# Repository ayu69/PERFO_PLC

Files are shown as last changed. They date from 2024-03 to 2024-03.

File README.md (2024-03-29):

# PERFO_PLC

Vous trouverez l'ensemble des schémas et routage des cartes

Bus Fond de panier :
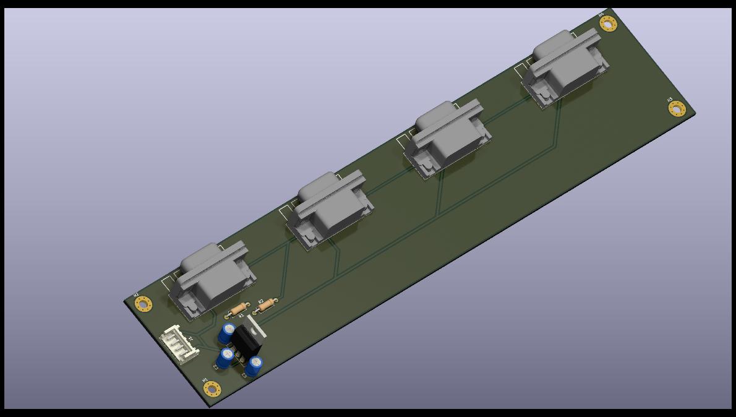
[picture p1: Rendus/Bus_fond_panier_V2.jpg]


CPU :
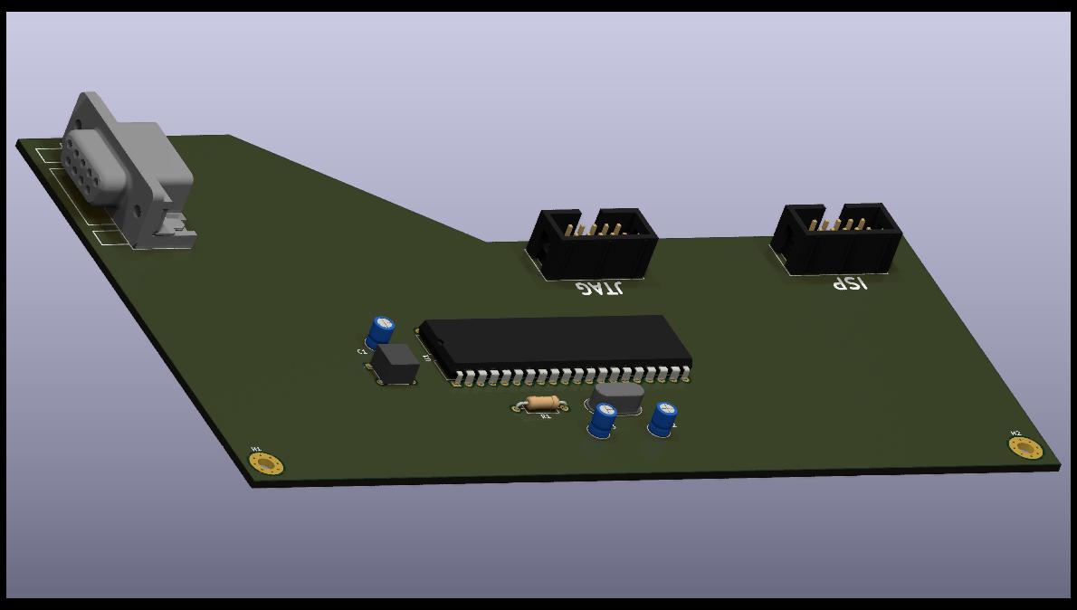
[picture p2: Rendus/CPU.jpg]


Carte Entrée :
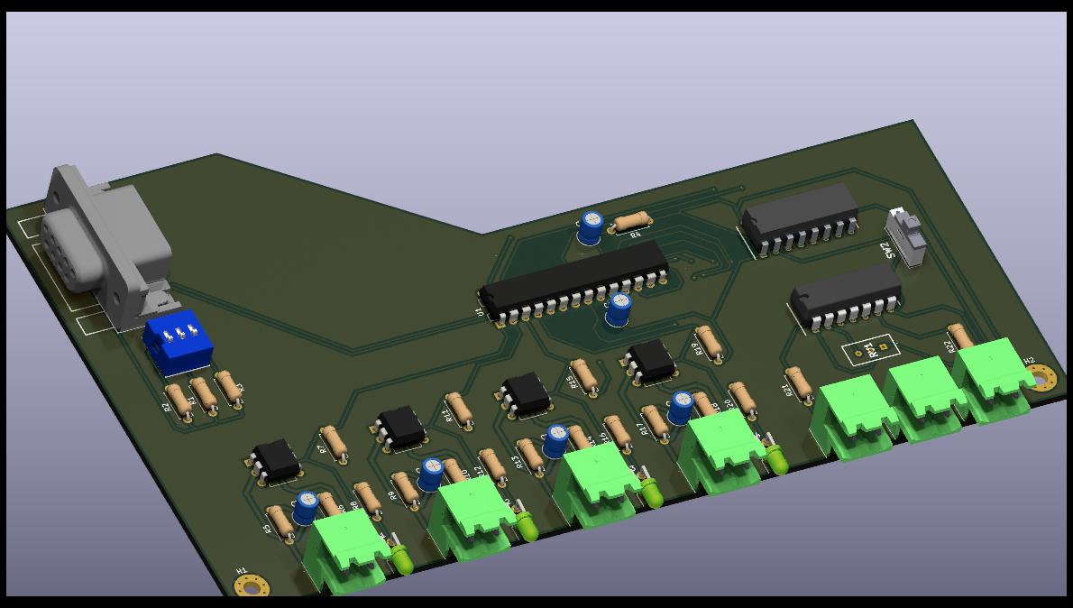
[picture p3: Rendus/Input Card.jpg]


Carte Sorties :
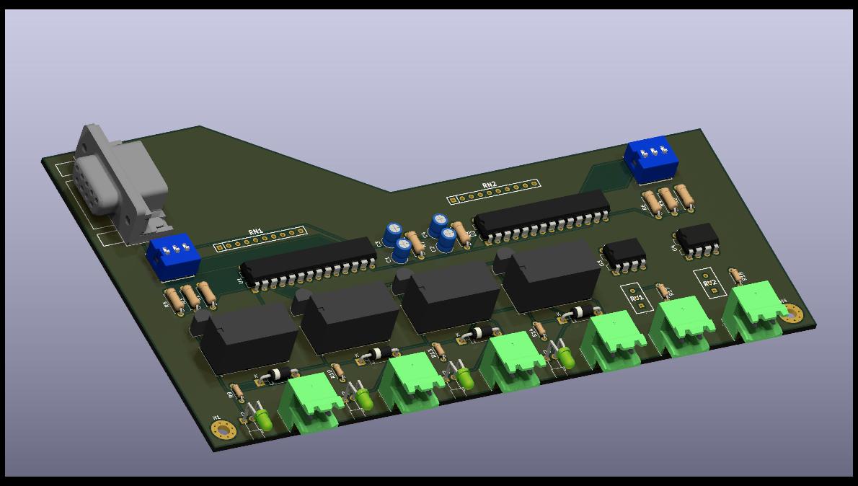
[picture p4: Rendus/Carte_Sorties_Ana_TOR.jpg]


Perfo PLC

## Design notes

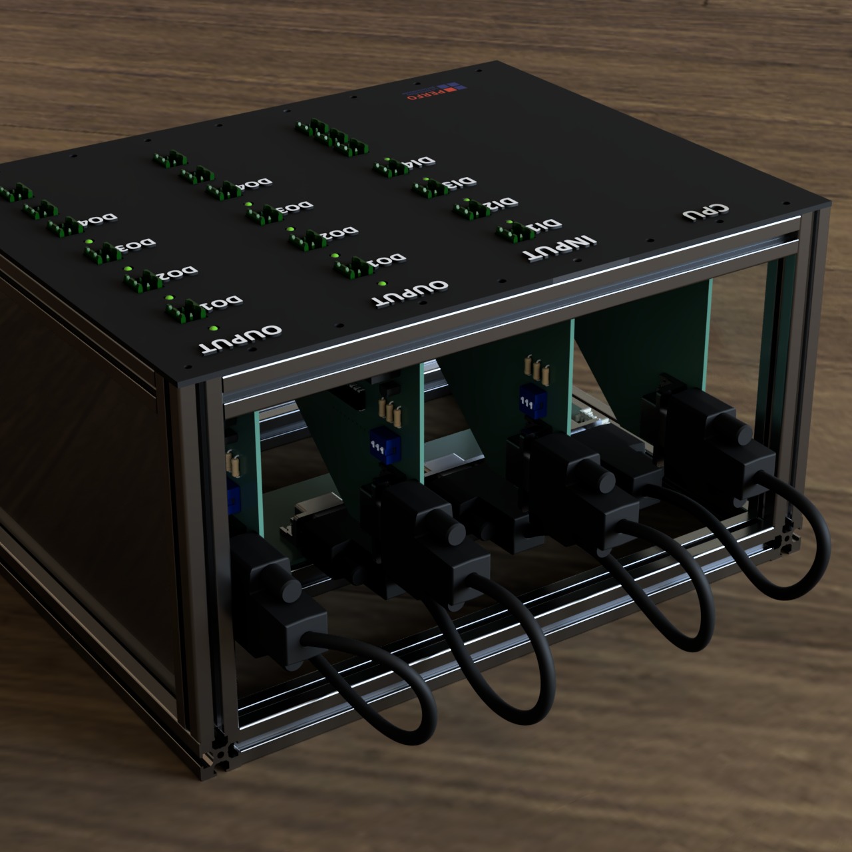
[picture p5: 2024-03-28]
Rendus/Rendu 2 V2.jpeg

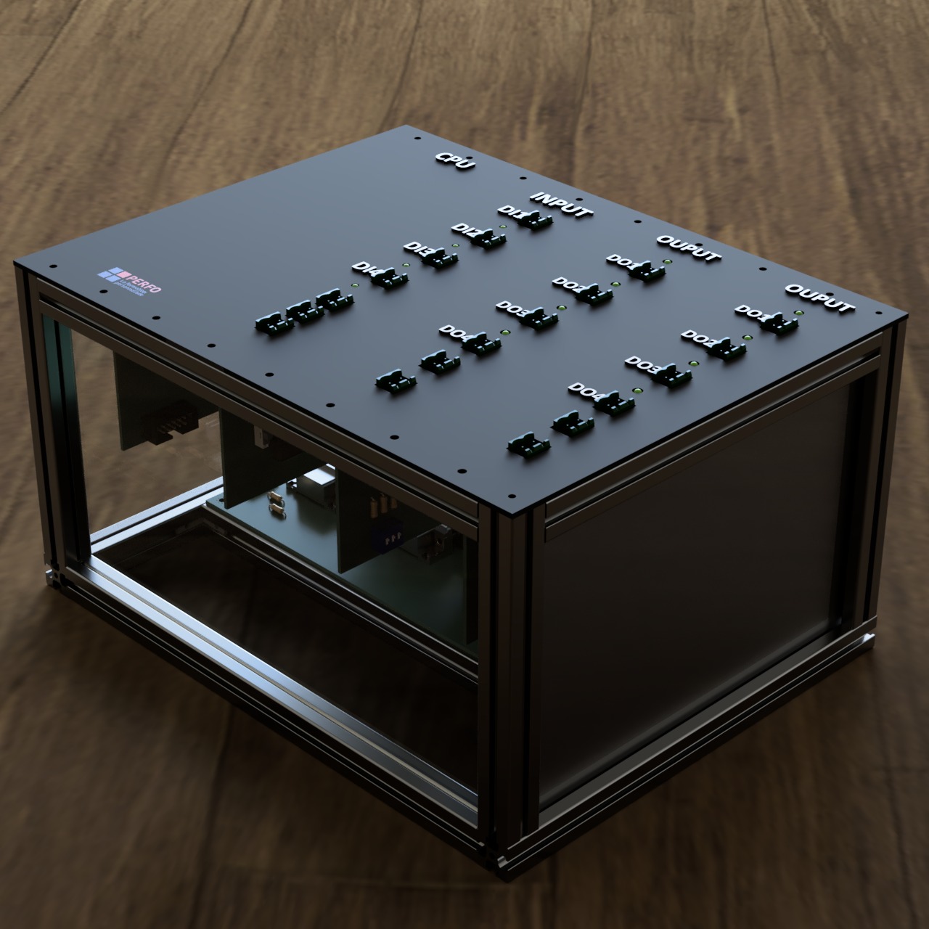
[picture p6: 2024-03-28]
Rendus/Rendu 1 V2.jpeg

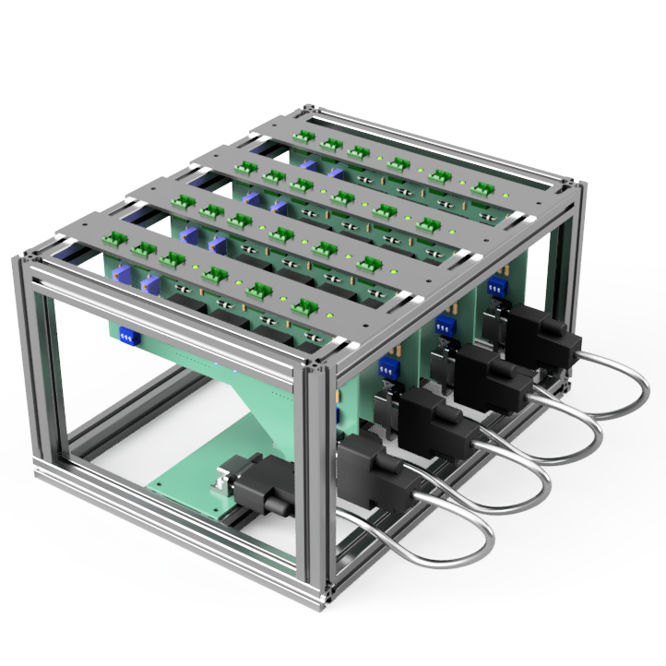
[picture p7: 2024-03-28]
Rendus/Rendu_1.png

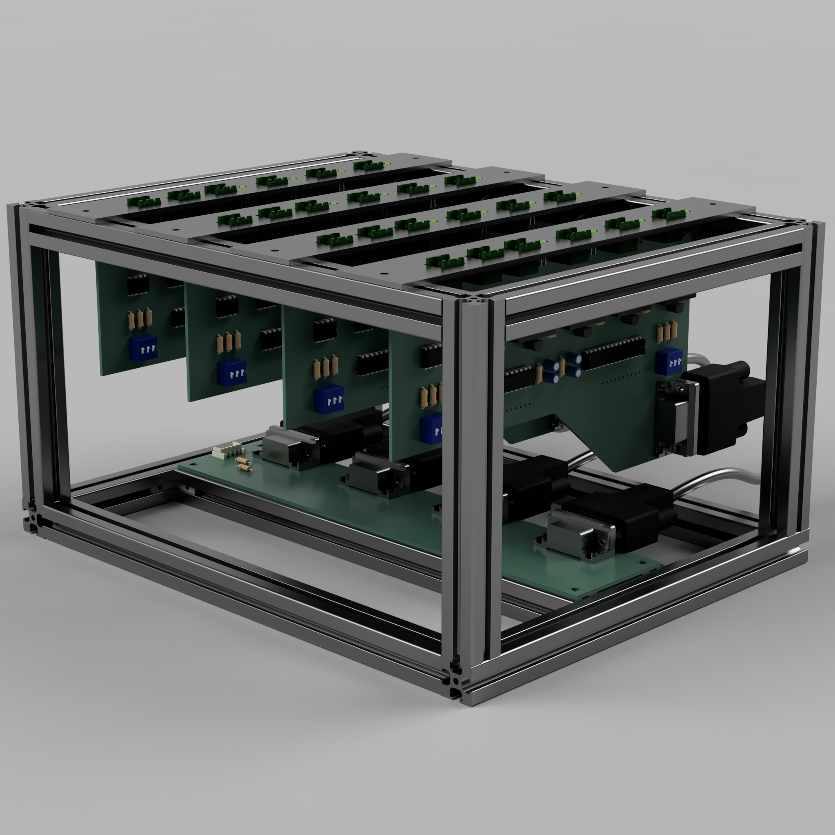
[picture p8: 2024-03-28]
Rendus/Rendu_2.png

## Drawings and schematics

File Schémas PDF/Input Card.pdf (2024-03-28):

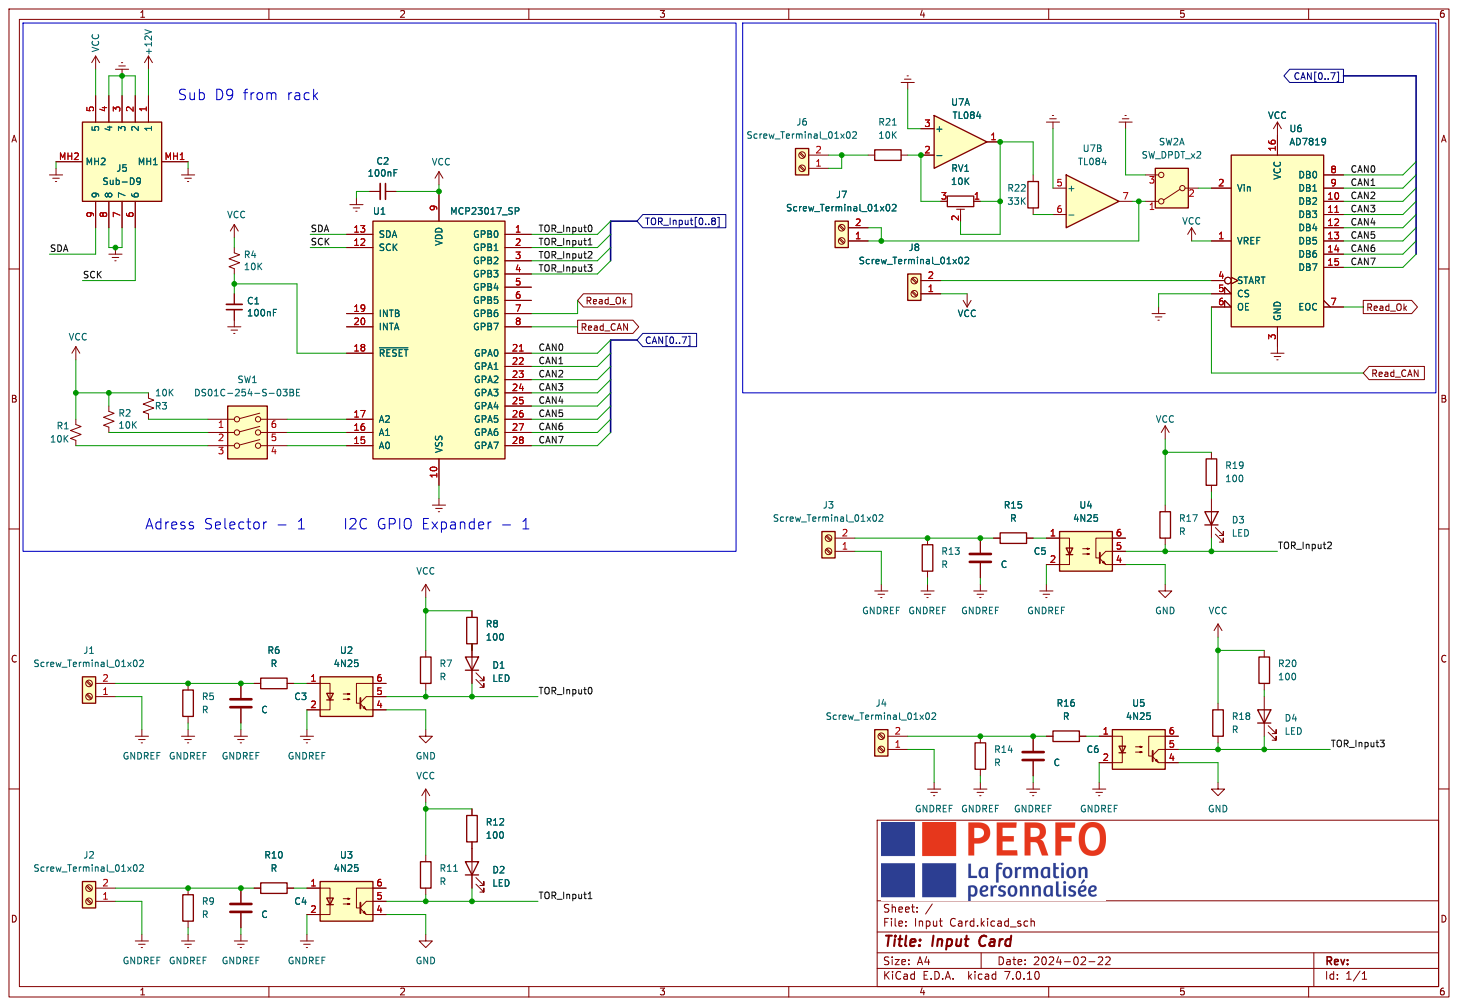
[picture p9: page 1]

3 START 4 CS 5 OE 6 EOC 7 DB0 8 DB1 9 U6AD7819 GNDREF GND

3 START 4 CS 5 OE 6 EOC 7 DB0 8 DB1 9

File: Input Card.kicad_sch Sheet: / 1

Id: 1/1 Title: Input Card

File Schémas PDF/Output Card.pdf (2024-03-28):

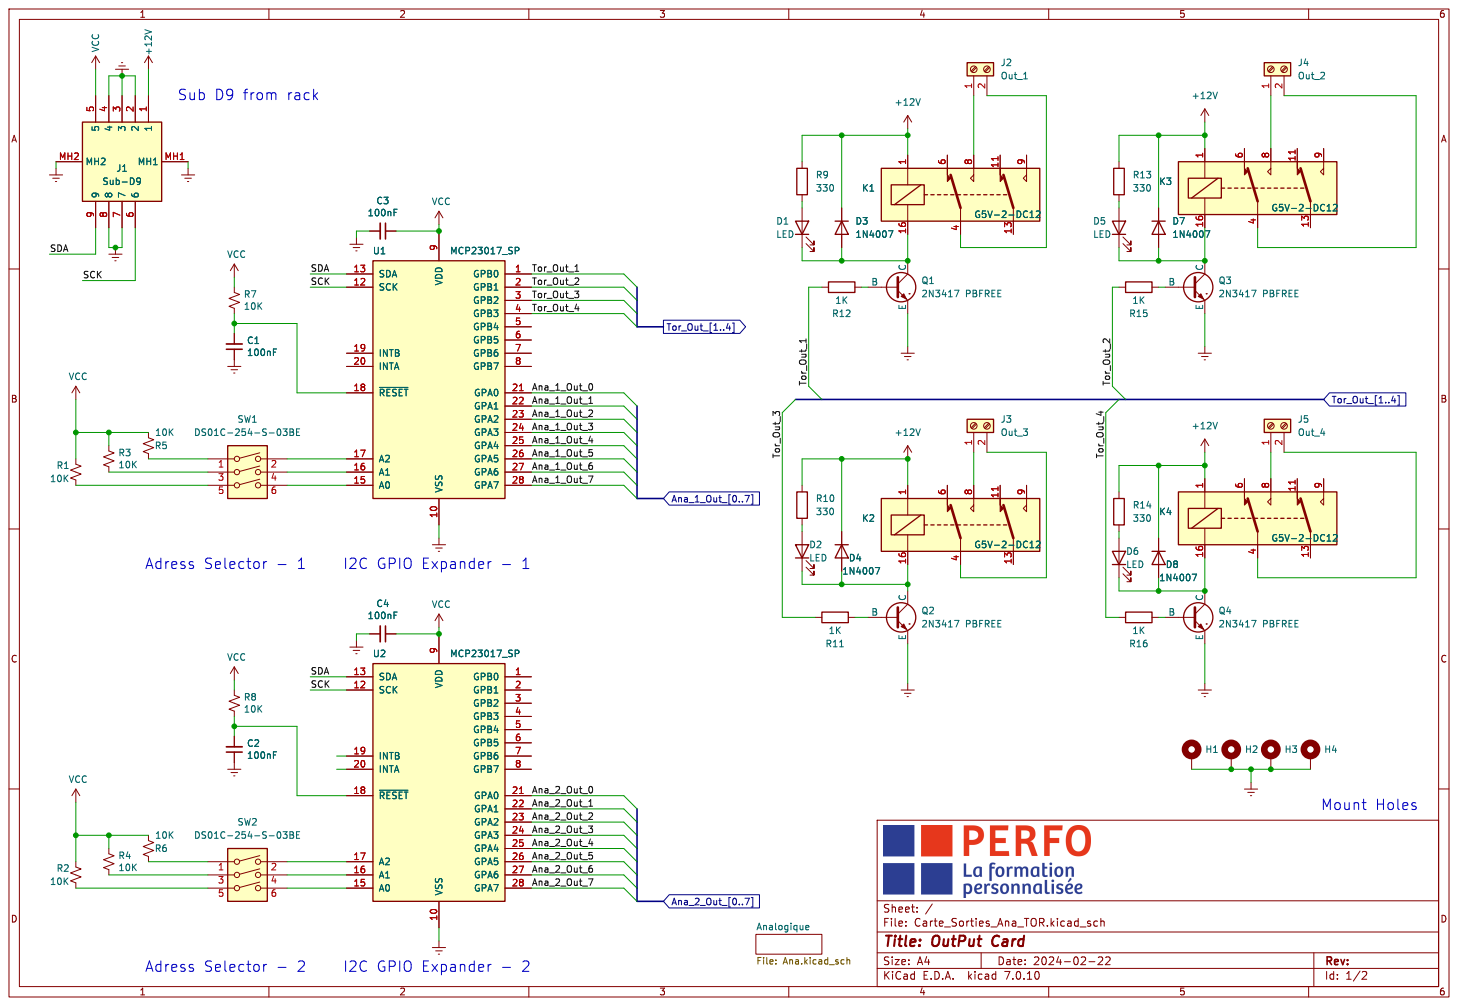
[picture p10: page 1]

9 K3 G5V-2-DC12 GPB0 1 VSS 10 SCK 12 SDA 13 A0 15 A1 16 A2 17 ~{RESET} 18

9 K2 G5V-2-DC12 VCC GPB0 1 VSS 10 SCK 12 SDA 13 A0 15 A1 16 A2 17 ~{RESET} 18

File: Carte_Sorties_Ana_TOR.kicad_sch Sheet: / Analogique File: Ana.kicad_sch

Id: 1/2 Title: OutPut Card

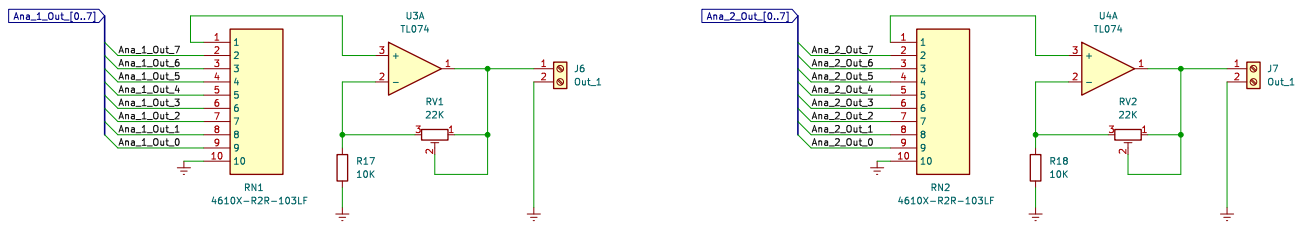
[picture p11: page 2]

File: Ana.kicad_sch Sheet: /Analogique/
Id: 2/2 Title: OutPut Card

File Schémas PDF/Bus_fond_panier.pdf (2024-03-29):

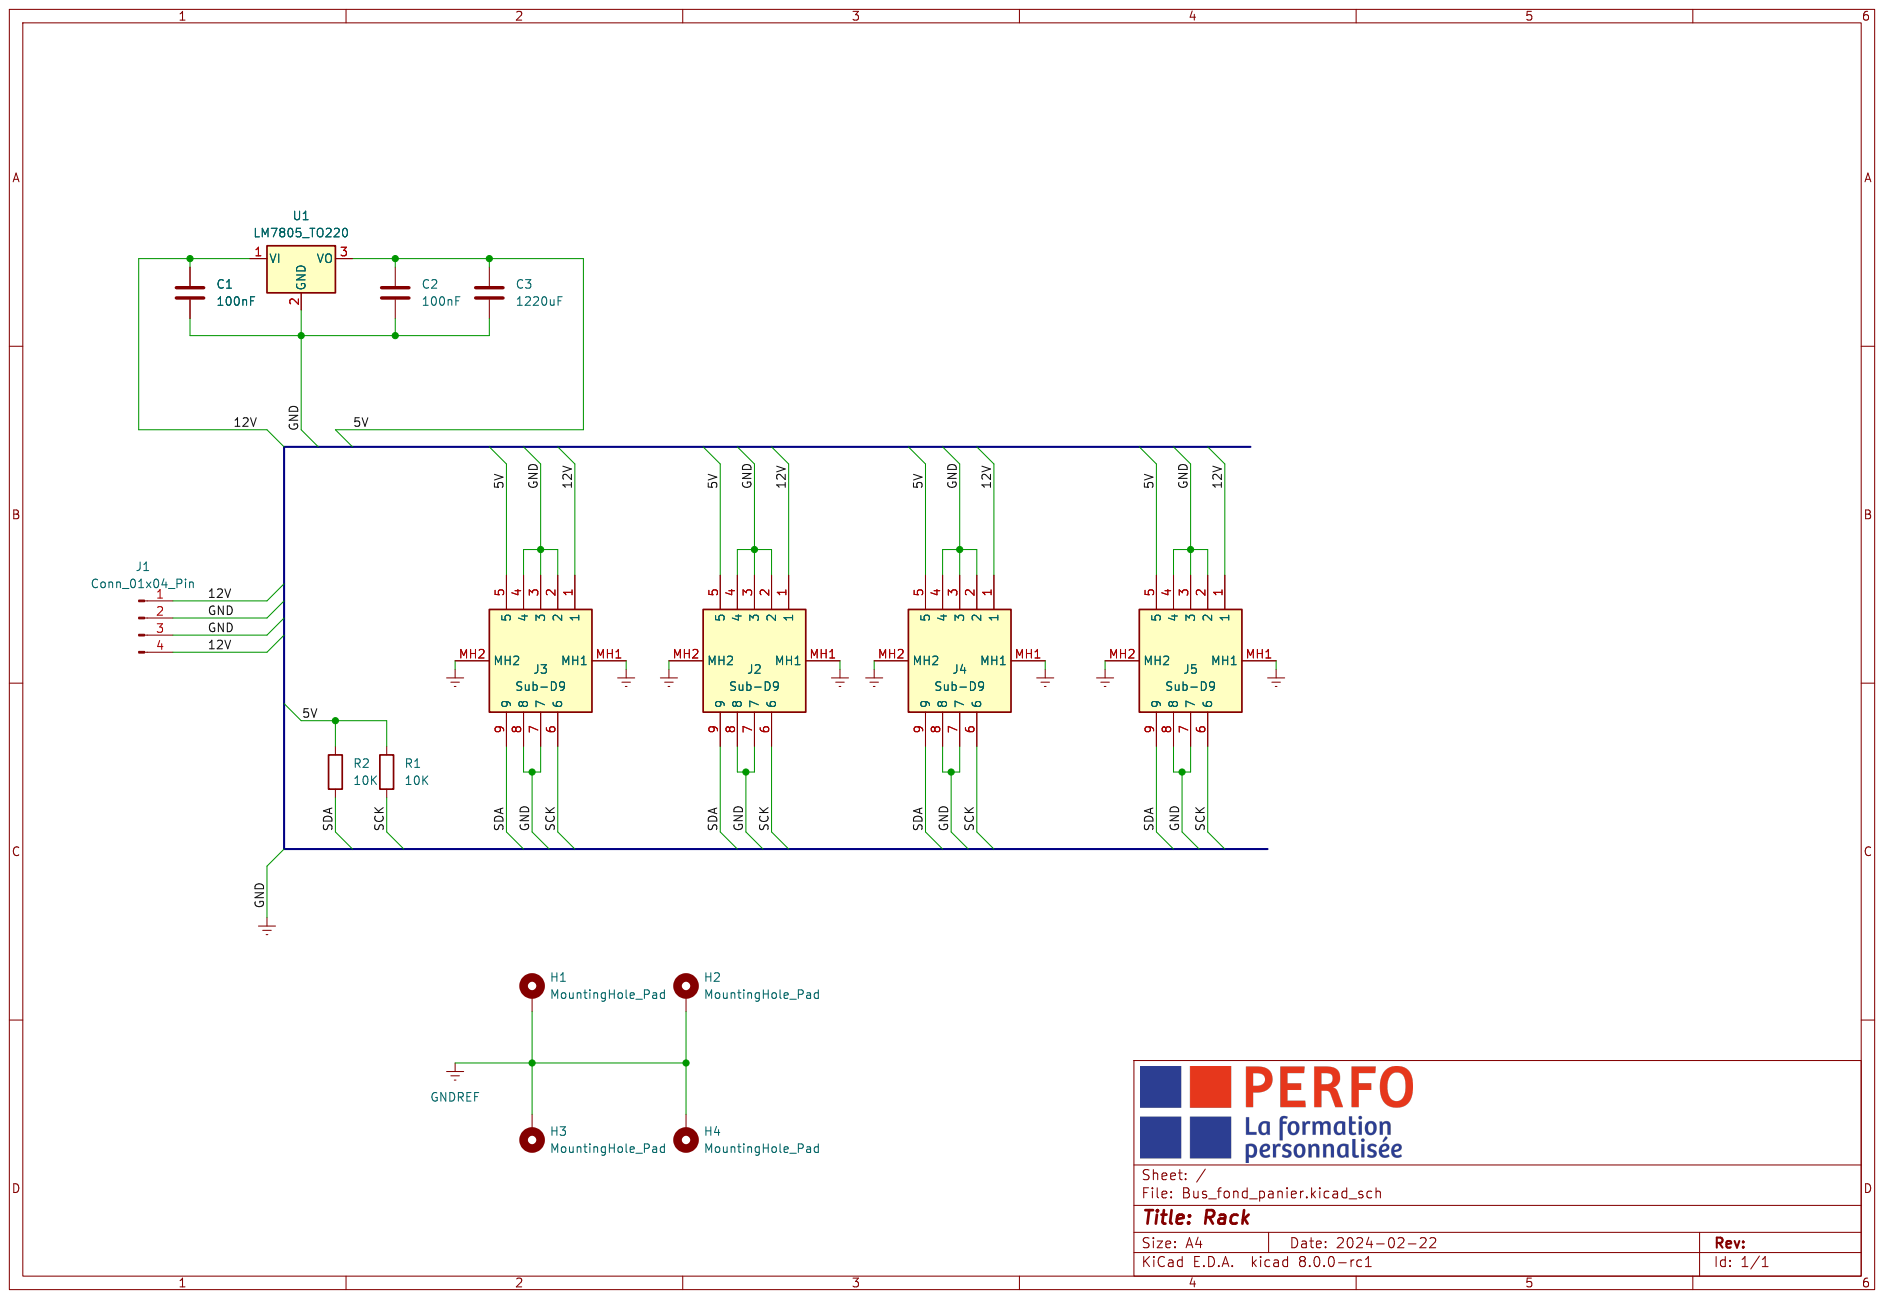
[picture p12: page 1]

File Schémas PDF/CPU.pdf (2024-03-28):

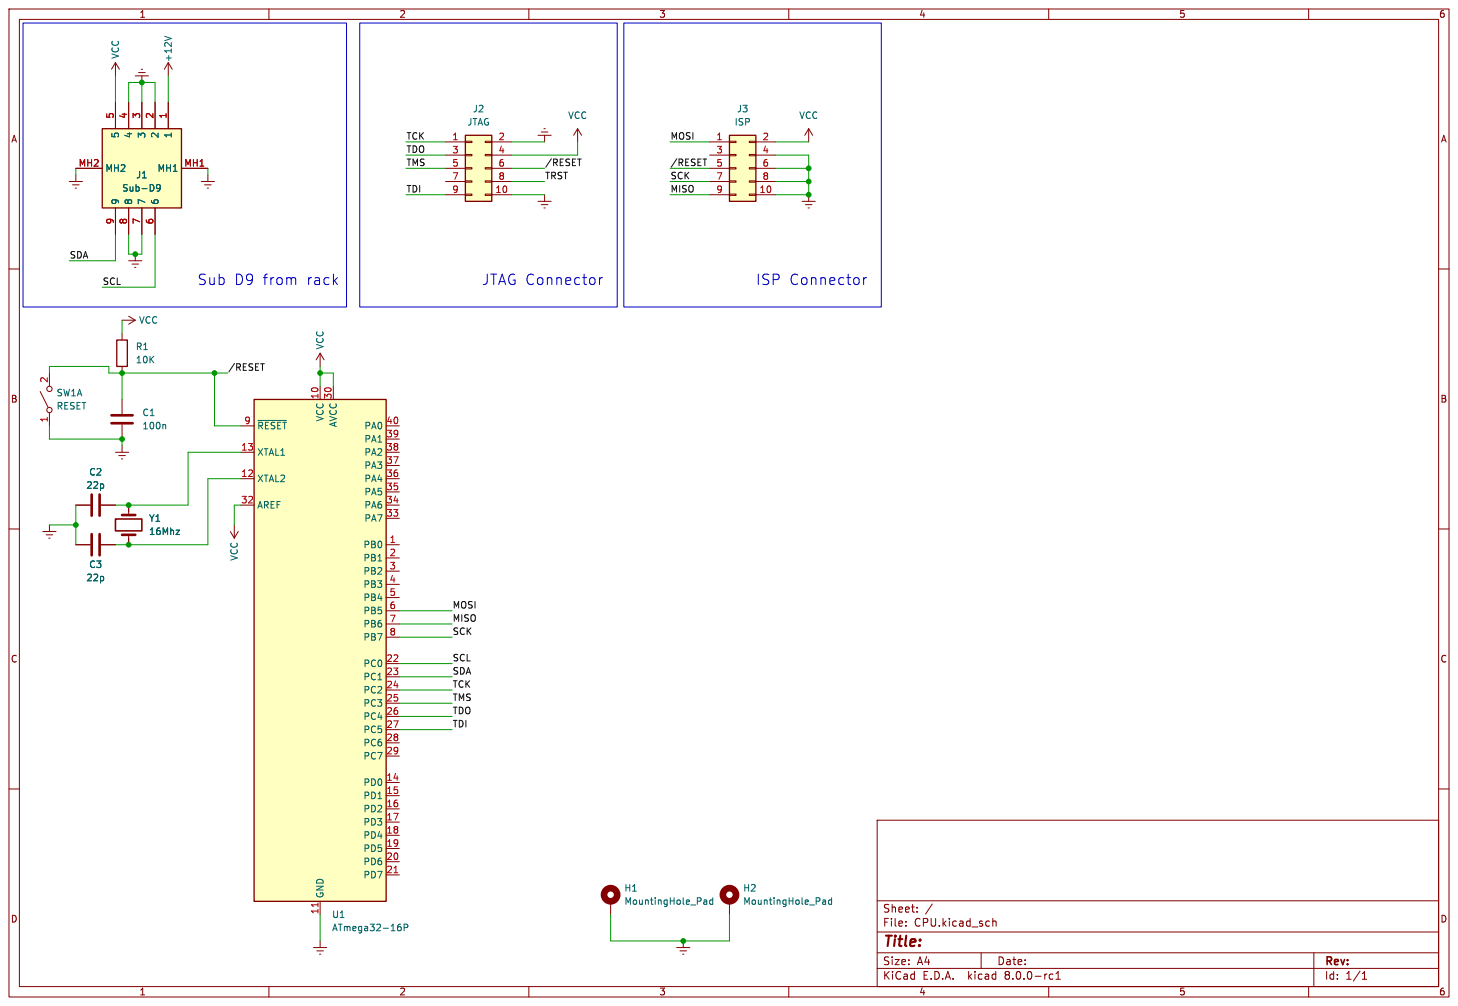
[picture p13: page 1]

/RESET SCK MISO MOSI TMS

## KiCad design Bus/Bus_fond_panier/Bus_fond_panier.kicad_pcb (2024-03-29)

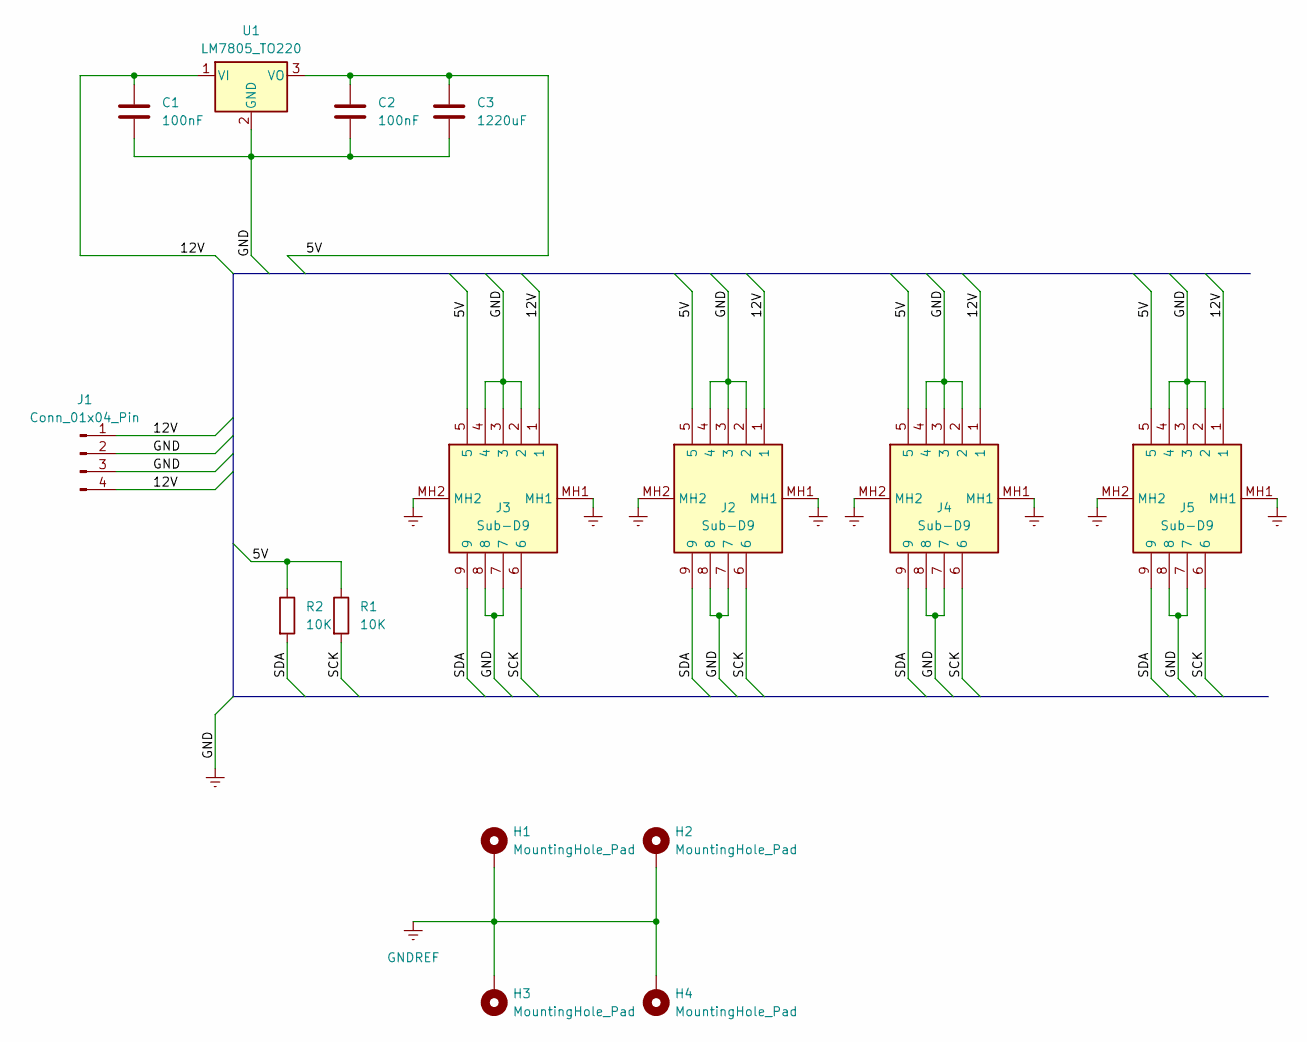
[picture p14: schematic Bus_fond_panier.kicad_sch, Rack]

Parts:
C1, C2: 100nF; C_Radial_D4.0mm_H7.0mm_P1.50mm
C3: 1220uF; C_Radial_D4.0mm_H7.0mm_P1.50mm
H1, H2, H3, H4: MountingHole_Pad; MountingHole_3.2mm_M3_Pad_Via
J1: Conn_01x04_Pin; JST_EH_S4B-EH_1x04_P2.50mm_Horizontal
J2, J3, J4, J5: Sub-D9; NFD17E09SAFC1DA; Manufacturer_Part_Number NFD17E09SAFC1DA
R1, R2: 10K; R_Axial_DIN0207_L6.3mm_D2.5mm_P10.16mm_Horizontal
U1: LM7805_TO220; TO-220-3_Vertical

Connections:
/5V: C2.1, C3.1, J2.5, J3.5, J4.5, J5.5, R1.1, R2.1, U1.3 (VO)
/12V: C1.1, J1.1, J1.4, J2.1, J3.1, J4.1, J5.1, U1.1 (VI)
/SCK: J2.6, J3.6, J4.6, J5.6, R1.2
/SDA: J2.9, J3.9, J4.9, J5.9, R2.2
GNDREF: C1.2, C2.2, C3.2, H1.1, H2.1, H3.1, H4.1, J1.2, J1.3, J2.2, J2.3, J2.4, J2.7, J2.8, J2.MH1, J2.MH2, J3.2, J3.3, J3.4, J3.7, J3.8, J3.MH1, J3.MH2, J4.2, J4.3, J4.4, J4.7, J4.8, J4.MH1, J4.MH2, J5.2, J5.3, J5.4, J5.7, J5.8, J5.MH1, J5.MH2, U1.2 (GND)

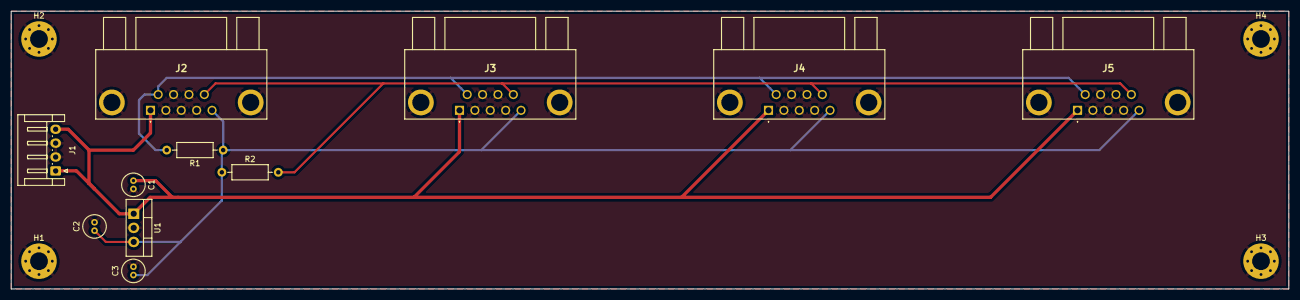
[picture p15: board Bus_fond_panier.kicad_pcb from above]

Board: 2 copper layers, 230.0 x 50.0 mm, 15 parts (0 on the bottom side), 5 nets.

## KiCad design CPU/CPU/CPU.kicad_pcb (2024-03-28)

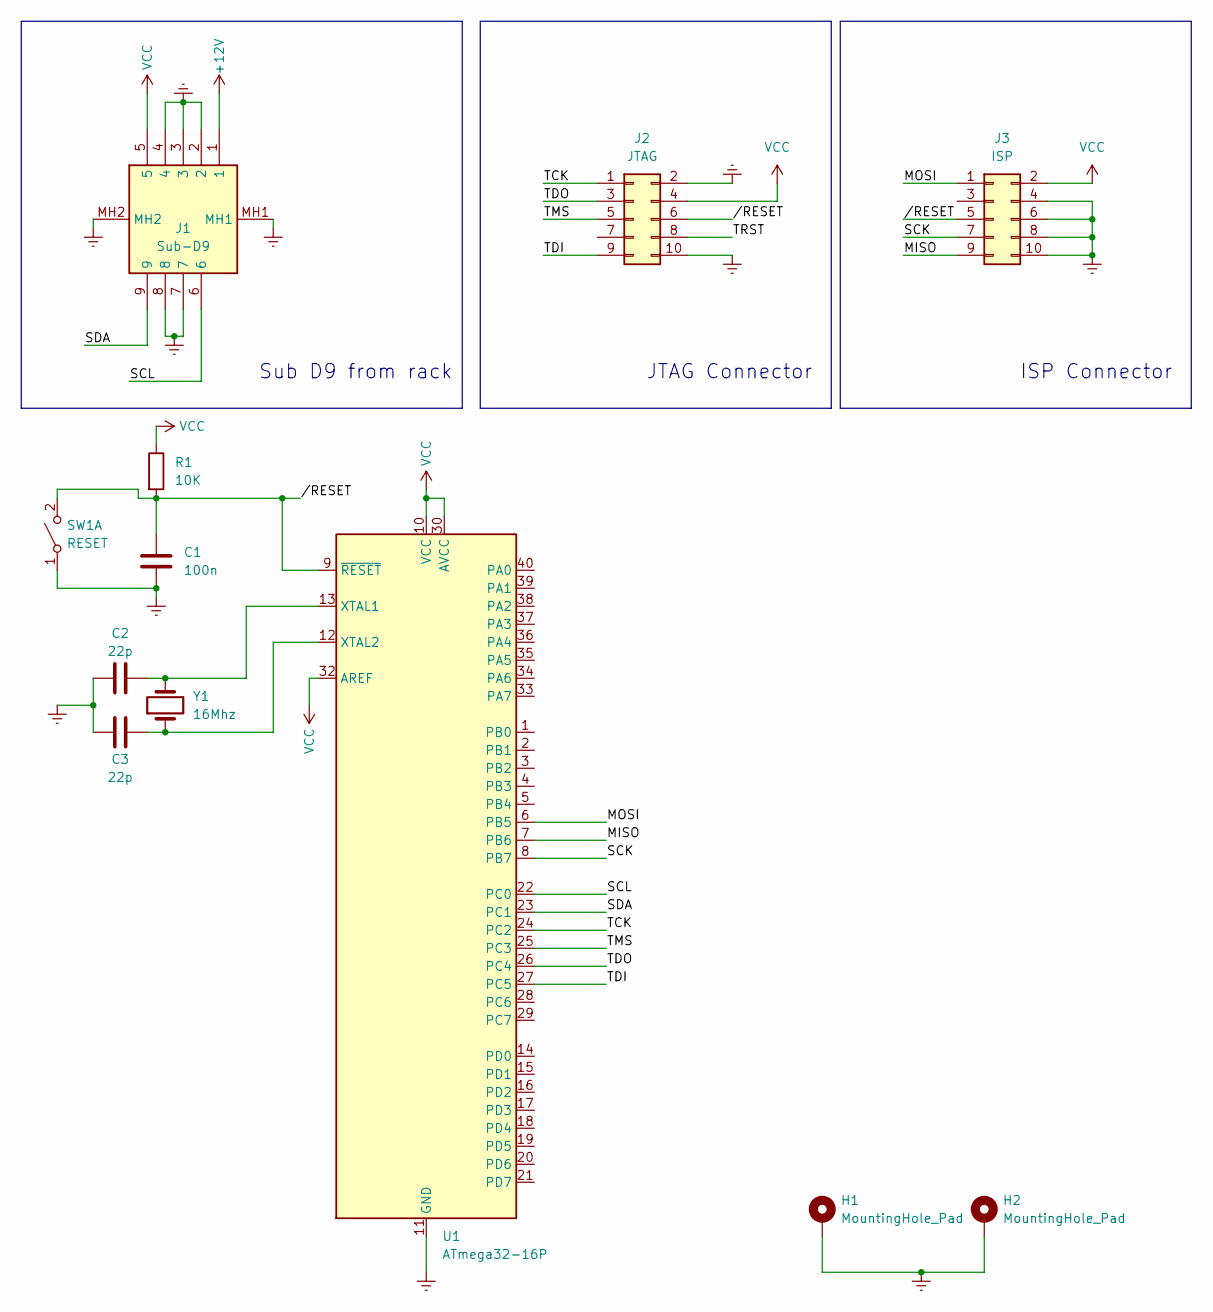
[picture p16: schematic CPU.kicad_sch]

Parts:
C1: 100n; C_Radial_D4.0mm_H5.0mm_P1.50mm
C2, C3: 22p; C_Radial_D4.0mm_H5.0mm_P1.50mm
H1, H2: MountingHole_Pad; MountingHole_3.2mm_M3_Pad_Via
J1: Sub-D9; NFD17E09SAFC1DA; Manufacturer_Part_Number NFD17E09SAFC1DA
J2: JTAG; IDC-Header_2x05_P2.54mm_Vertical
J3: ISP; IDC-Header_2x05_P2.54mm_Vertical
R1: 10K; R_Axial_DIN0207_L6.3mm_D2.5mm_P10.16mm_Horizontal
SW1: RESET; PTS645SH952LFS
U1: ATmega32-16P; DIP-40_W15.24mm
Y1: 16Mhz; Crystal_HC49-4H_Vertical

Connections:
+12V: J1.1
/MISO: J3.9, U1.7 (PB6)
/MOSI: J3.1, U1.6 (PB5)
/SCK: J3.7, U1.8 (PB7)
/SCL: J1.6, U1.22 (PC0)
/SDA: J1.9, U1.23 (PC1)
/TCK: J2.1, U1.24 (PC2)
/TDI: J2.9, U1.27 (PC5)
/TDO: J2.3, U1.26 (PC4)
/TMS: J2.5, U1.25 (PC3)
/TRST: J2.8
//RESET: C1.1, J2.6, J3.5, R1.2, SW1.2 (B), U1.9 (~RESET)
GNDREF: C1.2, C2.1, C3.1, H1.1, H2.1, J1.2, J1.3, J1.4, J1.7, J1.8, J1.MH1, J1.MH2, J2.2, J2.10, J3.4, J3.6, J3.8, J3.10, SW1.1 (A), U1.11 (GND), U1.31 (GND)
unnamed: C2.2, U1.13 (XTAL1), Y1.2
unnamed: C3.2, U1.12 (XTAL2), Y1.1
VCC: J1.5, J2.4, J3.2, R1.1, U1.10 (VCC), U1.30 (AVCC), U1.32 (AREF)

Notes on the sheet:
JTAG Connector
Sub D9 from rack
ISP Connector

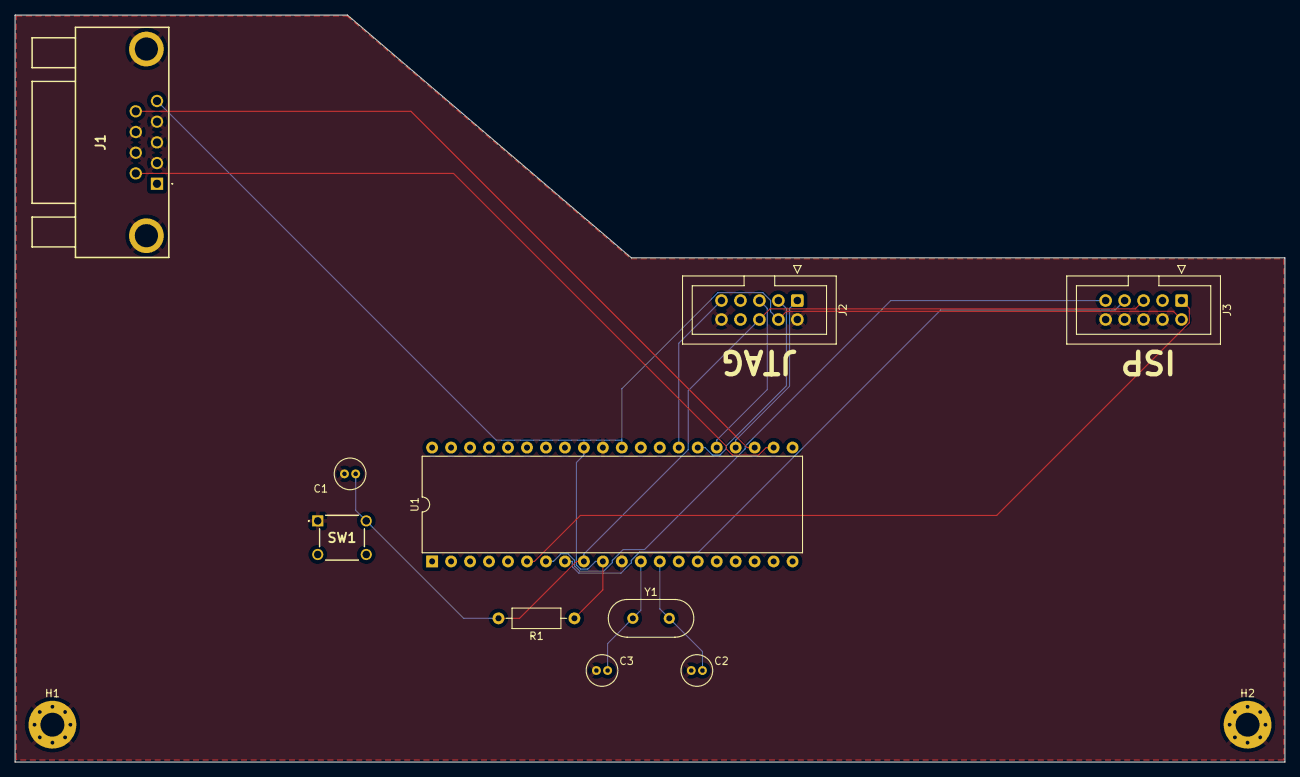
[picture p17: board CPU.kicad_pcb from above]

Board: 2 copper layers, 170.0 x 100.0 mm, 12 parts (0 on the bottom side), 14 nets.

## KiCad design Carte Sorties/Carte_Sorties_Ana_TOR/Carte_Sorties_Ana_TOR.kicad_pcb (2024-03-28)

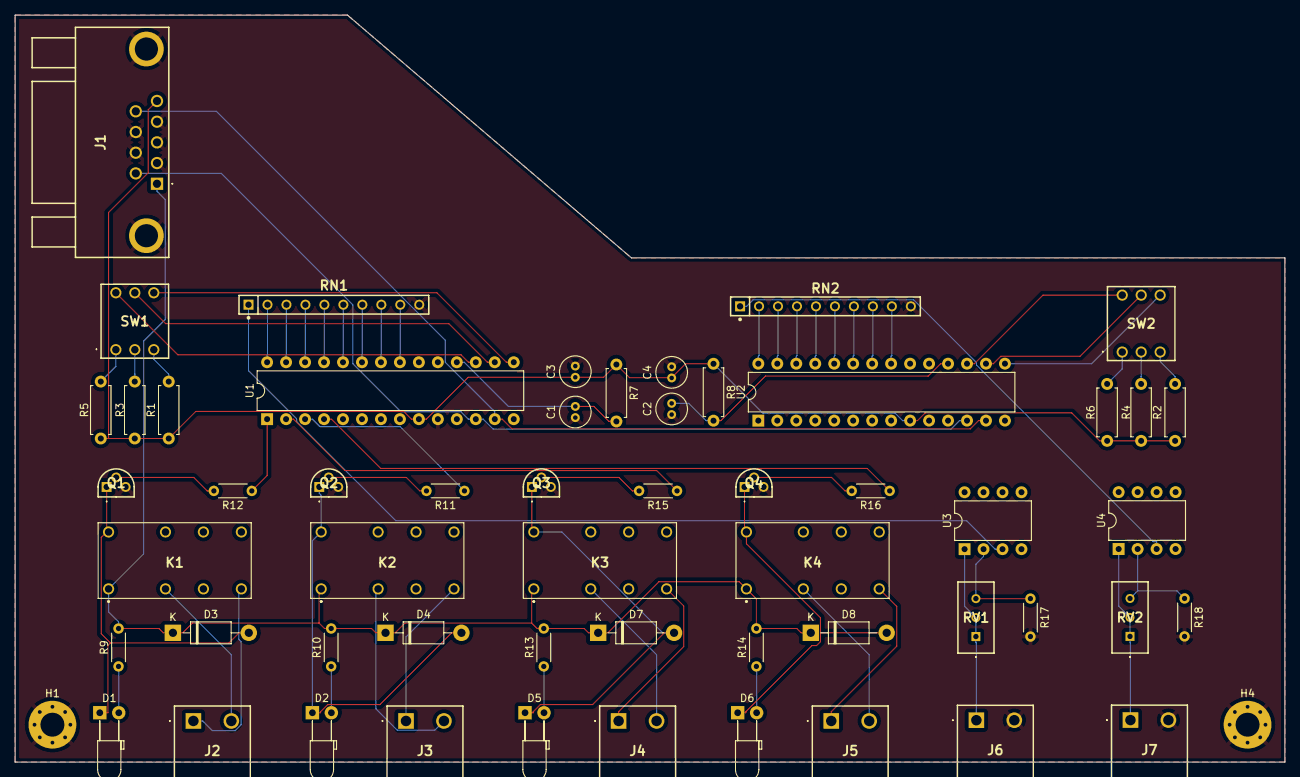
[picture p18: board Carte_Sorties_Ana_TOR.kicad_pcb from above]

Board: 2 copper layers, 170.0 x 100.0 mm, 57 parts (0 on the bottom side), 65 nets.

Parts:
C1, C2, C3, C4: 100nF; C_Radial_D4.0mm_H5.0mm_P1.50mm
D1, D2, D5, D6: LED; LED_D3.0mm_Horizontal_O3.81mm_Z6.0mm
D3, D4, D7, D8: 1N4007; D_DO-41_SOD81_P10.16mm_Horizontal
H1, H4: MountingHole_Pad; MountingHole_3.2mm_M3_Pad_Via
J1: Sub-D9; NFD17E09SAFC1DA
J2, J6, J7: Out_1; 1735882
J3: Out_3; 1735882
J4: Out_2; 1735882
J5: Out_4; 1735882
K1, K2, K3, K4: G5V-2-DC12; G5V23DC
Q1, Q2, Q3, Q4: 2N3417 PBFREE; 2N3417PBFREE
R1, R2, R3, R4, R5, R6, R7, R8: 10K; R_Axial_DIN0207_L6.3mm_D2.5mm_P7.62mm_Horizontal
R9, R10, R13, R14: 330; R_Axial_DIN0204_L3.6mm_D1.6mm_P5.08mm_Horizontal
R11, R12, R15, R16: 1K; R_Axial_DIN0204_L3.6mm_D1.6mm_P5.08mm_Horizontal
R17, R18: 10K; R_Axial_DIN0204_L3.6mm_D1.6mm_P5.08mm_Horizontal
RN1, RN2: 4610X-R2R-103LF; SIP249W51P254L2535H508Q10P
RV1, RV2: 22K; 3296W1223LF
SW1, SW2: DS01C-254-S-03BE; DS01C254S03BE
U1, U2: MCP23017_SP; DIP-28_W7.62mm
U3, U4: TL074; DIP-8_W7.62mm

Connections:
+12V: D3.1 (K), D4.1 (K), D7.1 (K), D8.1 (K), J1.1, K1.1, K2.1, K3.1, K4.1, R9.2, R10.2, R13.2, R14.2
/SCK: J1.6, U1.12 (SCK), U2.12 (SCK)
/SDA: J1.9, U1.13 (SDA), U2.13 (SDA)
Ana_1_Out_0: RN1.9, U1.21 (GPA0)
Ana_1_Out_1: RN1.8, U1.22 (GPA1)
Ana_1_Out_2: RN1.7, U1.23 (GPA2)
Ana_1_Out_3: RN1.6, U1.24 (GPA3)
Ana_1_Out_4: RN1.5, U1.25 (GPA4)
Ana_1_Out_5: RN1.4, U1.26 (GPA5)
Ana_1_Out_6: RN1.3, U1.27 (GPA6)
Ana_1_Out_7: RN1.2, U1.28 (GPA7)
Ana_2_Out_0: RN2.9, U2.21 (GPA0)
Ana_2_Out_1: RN2.8, U2.22 (GPA1)
Ana_2_Out_2: RN2.7, U2.23 (GPA2)
Ana_2_Out_3: RN2.6, U2.24 (GPA3)
Ana_2_Out_4: RN2.5, U2.25 (GPA4)
Ana_2_Out_5: RN2.4, U2.26 (GPA5)
Ana_2_Out_6: RN2.3, U2.27 (GPA6)
Ana_2_Out_7: RN2.2, U2.28 (GPA7)
GNDREF: C1.1, C2.1, C3.2, C4.2, H1.1, H4.1, J1.2, J1.3, J1.4, J1.7, J1.8, J1.MH1, J1.MH2, J6.2, J7.2, Q1.3 (E), Q2.3 (E), Q3.3 (E), Q4.3 (E), R17.2, R18.2, RN1.10, RN2.10, U1.10 (VSS), U2.10 (VSS)
unnamed: D1.2 (A), R9.1
unnamed: D1.1 (K), D3.2 (A), K1.16, Q1.1 (C)
unnamed: D2.2 (A), R10.1
unnamed: D2.1 (K), D4.2 (A), K2.16, Q2.1 (C)
unnamed: D5.2 (A), R13.1
unnamed: D5.1 (K), D7.2 (A), K3.16, Q3.1 (C)
unnamed: D6.2 (A), R14.1
unnamed: D6.1 (K), D8.2 (A), K4.16, Q4.1 (C)
unnamed: J2.1, K1.8
unnamed: J2.2, K1.4
unnamed: J3.1, K2.8
unnamed: J3.2, K2.4
unnamed: J4.1, K3.8
unnamed: J4.2, K3.4
unnamed: J5.1, K4.8
unnamed: J5.2, K4.4
unnamed: J6.1, RV1.1, RV1.2, U3.1
unnamed: J7.1, RV2.1, RV2.2, U4.1
unnamed: Q1.2 (B), R12.2
unnamed: Q2.2 (B), R11.2
unnamed: Q3.2 (B), R15.2
unnamed: Q4.2 (B), R16.2
unnamed: R1.2, SW1.5
unnamed: R2.2, SW2.5
unnamed: R3.2, SW1.3
unnamed: R4.2, SW2.3
unnamed: R5.1, SW1.1
unnamed: R6.1, SW2.1
unnamed: SW1.6, U1.15 (A0)
unnamed: SW1.4, U1.16 (A1)
unnamed: SW1.2, U1.17 (A2)
unnamed: C1.2, R7.2, U1.18 (~RESET)
unnamed: SW2.6, U2.15 (A0)
unnamed: SW2.4, U2.16 (A1)
unnamed: SW2.2, U2.17 (A2)
unnamed: C2.2, R8.2, U2.18 (~RESET)
unnamed: RN1.1, U3.3 (+)
unnamed: R17.1, RV1.3, U3.2 (-)
unnamed: RN2.1, U4.3 (+)
unnamed: R18.1, RV2.3, U4.2 (-)
Tor_Out_1: R12.1, U1.1 (GPB0)
Tor_Out_2: R15.1, U1.2 (GPB1)
Tor_Out_3: R11.1, U1.3 (GPB2)
Tor_Out_4: R16.1, U1.4 (GPB3)
VCC: C3.1, C4.1, J1.5, R1.1, R2.1, R3.1, R4.1, R5.2, R6.2, R7.1, R8.1, U1.9 (VDD), U2.9 (VDD)

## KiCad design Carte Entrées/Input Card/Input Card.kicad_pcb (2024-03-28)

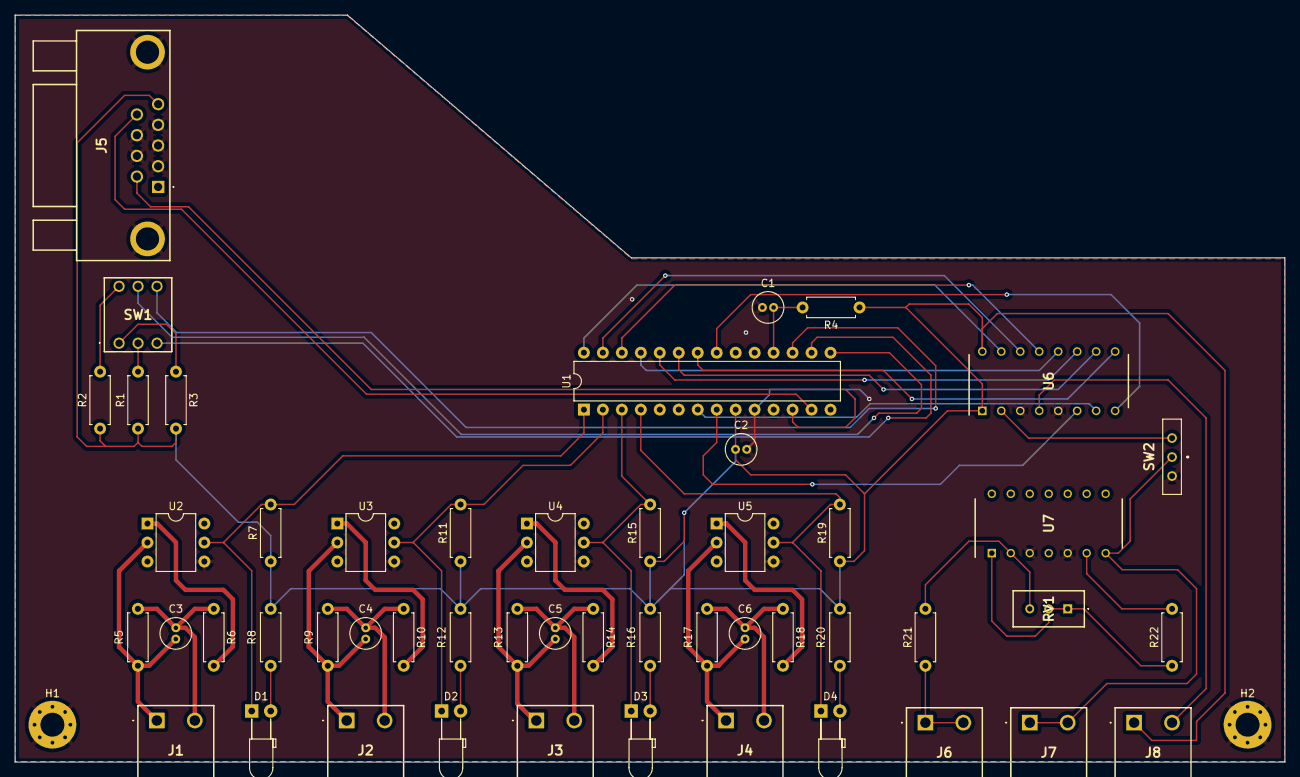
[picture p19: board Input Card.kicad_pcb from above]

Board: 2 copper layers, 170.0 x 100.0 mm, 52 parts (0 on the bottom side), 48 nets.

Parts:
C1, C2: 100nF; C_Radial_D4.0mm_H5.0mm_P1.50mm
C3, C4, C5, C6: C; C_Radial_D4.0mm_H5.0mm_P1.50mm
D1, D2, D3, D4: LED; LED_D3.0mm_Horizontal_O3.81mm_Z2.0mm
H1, H2: MountHole; MountingHole_3.2mm_M3_Pad_Via
J1, J2, J3, J4, J6, J7, J8: Screw_Terminal_01x02; 1735882
J5: Sub-D9; NFD17E09SAFC1DA
R1, R2, R3, R4, R21: 10K; R_Axial_DIN0207_L6.3mm_D2.5mm_P7.62mm_Horizontal
R5, R6, R7, R9, R10, R11, R13, R14, R15, R17, R18, R19: R; R_Axial_DIN0207_L6.3mm_D2.5mm_P7.62mm_Horizontal
R8, R12, R16, R20: 100; R_Axial_DIN0207_L6.3mm_D2.5mm_P7.62mm_Horizontal
R22: 33K; R_Axial_DIN0207_L6.3mm_D2.5mm_P7.62mm_Horizontal
RV1: 10K; 3296W1223LF
SW1: DS01C-254-S-03BE; DS01C254S03BE
SW2: SW_DPDT_x2; 090329001
U1: MCP23017_SP; DIP-28_W7.62mm
U2, U3, U4, U5: 4N25; DIP-6_W7.62mm
U6: AD7819; DIP794W56P254L2013H533Q16N
U7: TL084; DIP794W53P254L1930H508Q14N

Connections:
/GNDREF_1: C3.2, J1.1, R5.2, U2.2
/GNDREF_2: C4.2, J2.1, R9.2, U3.2
/GNDREF_3: C5.2, J3.1, R13.2, U4.2
/GNDREF_4: C6.2, J4.1, R17.2, U5.2
/SCK: J5.6, U1.12 (SCK)
/SDA: J5.9, U1.13 (SDA)
CAN0: U1.21 (GPA0), U6.8 (DB0)
CAN1: U1.22 (GPA1), U6.9 (DB1)
CAN2: U1.23 (GPA2), U6.10 (DB2)
CAN3: U1.24 (GPA3), U6.11 (DB3)
CAN4: U1.25 (GPA4), U6.12 (DB4)
CAN5: U1.26 (GPA5), U6.13 (DB5)
CAN6: U1.27 (GPA6), U6.14 (DB6)
CAN7: U1.28 (GPA7), U6.15 (DB7)
GNDREF: C1.1, C2.2, H1.1, H2.1, J5.2, J5.3, J5.4, J5.7, J5.8, J5.MH1, J5.MH2, SW2.3 (C), U1.10 (VSS), U2.4, U3.4, U4.4, U5.4, U6.3 (GND), U6.5 (CS), U7.3 (+), U7.5 (+)
unnamed: D1.2 (A), R8.2
unnamed: D2.2 (A), R12.2
unnamed: D3.2 (A), R16.2
unnamed: D4.2 (A), R20.2
unnamed: C3.1, J1.2, R5.1, R6.1
unnamed: C4.1, J2.2, R9.1, R10.1
unnamed: C5.1, J3.2, R13.1, R14.1
unnamed: C6.1, J4.2, R17.1, R18.1
unnamed: J6.1, J6.2, R21.1
unnamed: J7.1, J7.2, SW2.1 (A), U7.7
unnamed: J8.2, U6.4 (START)
unnamed: R1.2, SW1.3
unnamed: R2.2, SW1.2
unnamed: R3.1, SW1.1
unnamed: R6.2, U2.1
unnamed: R10.2, U3.1
unnamed: R14.2, U4.1
unnamed: R18.2, U5.1
unnamed: R22.1, RV1.1, RV1.2, U7.1
unnamed: SW2.2 (B), U6.2 (Vin)
unnamed: SW1.4, U1.15 (A0)
unnamed: SW1.5, U1.16 (A1)
unnamed: SW1.6, U1.17 (A2)
unnamed: C1.2, R4.2, U1.18 (~RESET)
unnamed: R21.2, RV1.3, U7.2 (-)
unnamed: R22.2, U7.6 (-)
Read_CAN: U1.8 (GPB7), U6.6 (OE)
Read_Ok: U1.7 (GPB6), U6.7 (EOC)
TOR_Input0: D1.1 (K), R7.2, U1.1 (GPB0), U2.5
TOR_Input1: D2.1 (K), R11.2, U1.2 (GPB1), U3.5
TOR_Input2: D3.1 (K), R15.2, U1.3 (GPB2), U4.5
TOR_Input3: D4.1 (K), R19.2, U1.4 (GPB3), U5.5
VCC: C2.1, J5.5, J8.1, R1.1, R2.1, R3.2, R4.1, R7.1, R8.1, R11.1, R12.1, R15.1, R16.1, R19.1, R20.1, U1.9 (VDD), U6.1 (VREF), U6.16 (VCC)
